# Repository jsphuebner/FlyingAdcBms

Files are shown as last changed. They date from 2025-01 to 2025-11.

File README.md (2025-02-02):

# Flying ADC BMS
This BMS senses up to 16 channels per board. Boards can be stacked to sense any number of cells. Each board has a current sensor input therefor the current sensor can be located where it is most convenient. In addition each board has two temperature sensor inputs.

For cell voltage sensing a single channel, high precision delta/sigma ADC is used in conjunction with a 16 channel multiplexer. Each cell is sensed with a differential input with an accuracy 0.5 mV. The ADC is paired with a full bridge connected to its 5V isolated power supply. This allows sending current into a low cell and also draining current from a high cell. Only small balancing currents are used over a long time thus omitting large power resistors.
Due to its architecture the cell inputs are somewhat tolerant to miswiring, i.e. a swapped cell lead or multiple cells across one input won't damage the circuitry and will instead be reported by software.

# Wiring
Each board has 17 inputs for cell taps labeled V0 to V16. The very first input of the first board is connected to B-, i.e. the negative pole of the most negative cell. V16 of the first board is connected to the positive pole of the 16th cell. The latter is also connected to V0 of the second board.
Not all channels of a board need to be used if it is more convenient

A common CAN bus and 12V supply is connected to each module. In addition each module has an enable input an output. The first enable input must be connected to 12V whenever you want the BMS to run. subsequent enable inputs are connected to the enable output of the previous module.

Further documentation can be found here: https://openinverter.org/wiki/16-cell_BMS

# OTA (over the air upgrade)
The firmware is linked to leave the 4 kb of flash unused. Those 4 kb are reserved for the bootloader
that you can find here: https://github.com/jsphuebner/stm32-CANBootloader/

When flashing your device for the first time you must first flash that bootloader. After that you can
use the ESP32 CAN module and its web interface to upload your actual application firmware.

The web interface is here: https://github.com/jsphuebner/esp32-web-interface/tree/can-backend

Binaries are here: https://github.com/jsphuebner/FlyingAdcBms/actions

# Compiling
You will need the arm-none-eabi toolchain: https://developer.arm.com/open-source/gnu-toolchain/gnu-rm/downloads
On Ubuntu type

`sudo apt-get install git gcc-arm-none-eabi`

The only external depedencies are libopencm3 and libopeninv. You can download and build these dependencies by typing

`make get-deps`

Now you can compile stm32-<yourname> by typing

`make`

And upload it to your board using a JTAG/SWD adapter, the updater.py script or the esp8266 web interface.

# Editing
The repository provides a project file for Code::Blocks, a rather leightweight IDE for cpp code editing.
For building though, it just executes the above command. Its build system is not actually used.
Consequently you can use your favority IDE or editor for editing files.

# Adding classes or modules
As your firmware grows you probably want to add classes. To do so, put the header file in include/ and the 
source file in src/ . Then add your module to the object list in Makefile that starts in line 43 with .o
extension. So if your files are called "mymodule.cpp" and "mymodule.h" you add "mymodule.o" to the list.

When changing a header file the build system doesn't always detect this, so you have to "make clean" and
then make. This is especially important when editing the "*_prj.h" files.

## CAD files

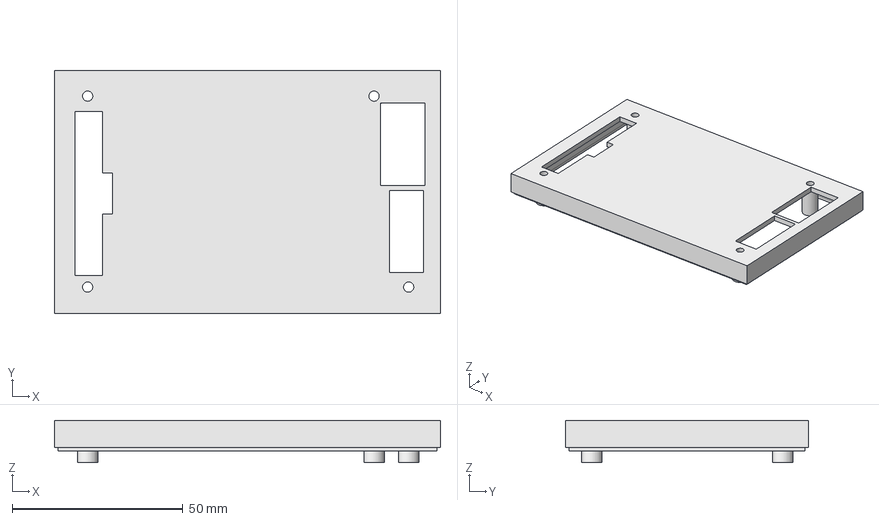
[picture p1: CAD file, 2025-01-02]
enclosure/Export/FlyingADCBMSCaseTop.step
113.0 x 71.0 x 12.3 mm

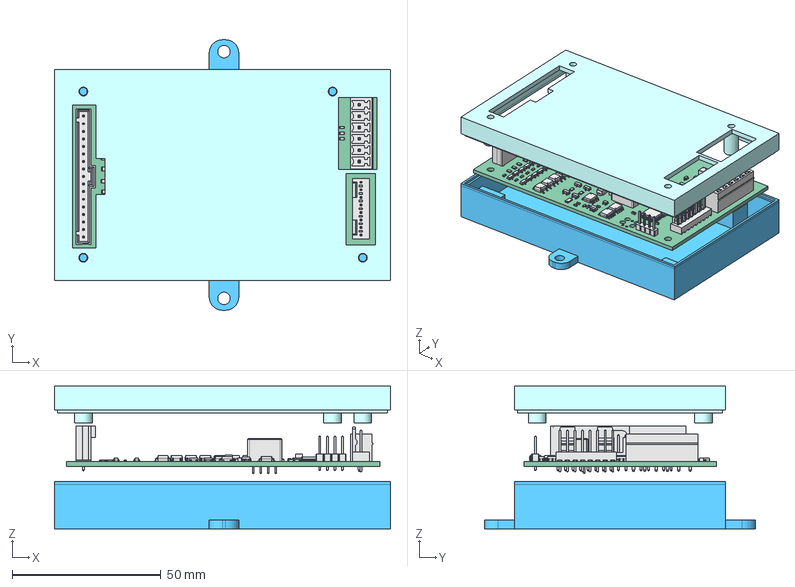
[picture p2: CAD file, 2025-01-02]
enclosure/Flying_ADC_BMS.FCStd
113.0 x 91.0 x 48.0 mm
Pcb_b294
Q14_SOT_23_87ded7d59d4a x 36
R14_R_0603_1608Metric_3bfc73a55aef x 30
R22_R_0805_2012Metric_596e45dfbf1c x 17
RN3_R_Array_Concave_4x0603_c5f54f47414b x 3
U27_SOP_4_38x41mm_P254mm_5cef88676b32 x 17
U6_SOIC_8_39x49mm_P127mm_981808474e07 x 4
J2_Molex_AE_6410_08A_b38d527fb858
L1_L_1210_3225Metric_4f8d756e5ff9
U2_SOT_23_6_b0798abddf9c x 2
C5_C_0805_2012Metric_f418098cded9 x 4
C7_C_0603_1608Metric_eb9e8be2ffff x 10
J5_PinHeader_1x04_P254mm_Vertical_e13bca67da23
D10_D_SMA_628cb4ce9e22
U15_SOT_353_SC_70_5_34e62e0b32b6
U14_LQFP_48_7x7mm_P05mm_7ef63f9fbcc2
F1_Fuse_1206_3216Metric_5dfb2dddf364
U4_SOIC_16_39x99mm_P127mm_1f1714147c6b x 2
PS1_Converter_DCDC_muRata_CRE1xxxxxx3C_THT_27c79fee6e5f[2]
J3_MCV_01x06_G_3_81mm_6525aa7bb5dd
D8_D_0805_f81e565784b3
L2_L_0805_2012Metric_366ff494121c
D6_D_SOD_323_b7a4576a8f9d x 2
CaseTop
CaseBottom

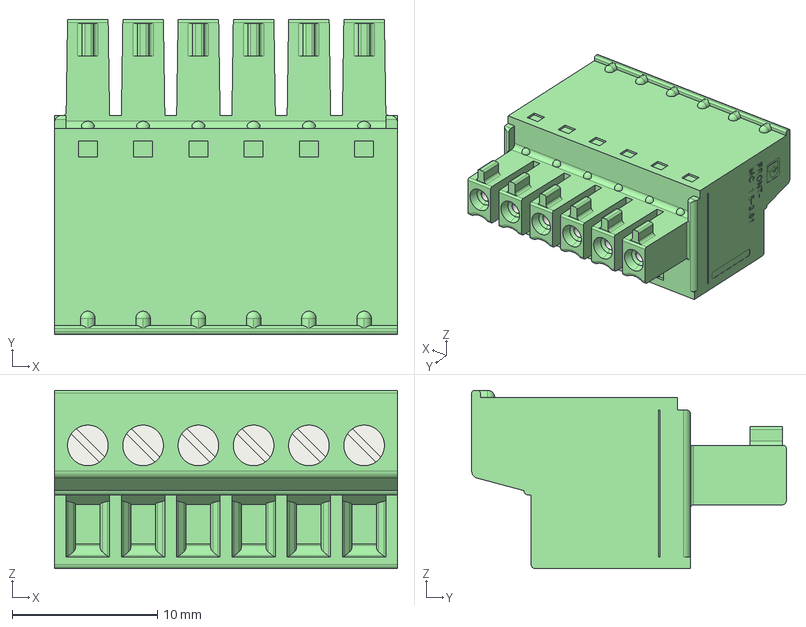
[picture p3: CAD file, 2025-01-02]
enclosure/Parts/pxc_1850709_13_FRONT-MC-1-5-6-ST-3-81_3D.stp
23.7 x 21.7 x 12.3 mm

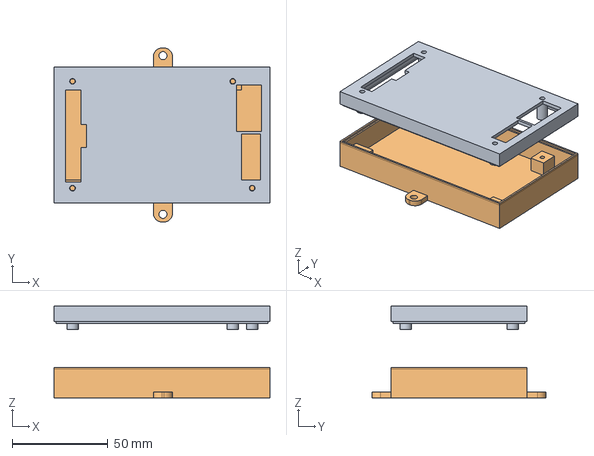
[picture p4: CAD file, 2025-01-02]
enclosure/Export/Flying_ADC_BMS_Case.step
113.0 x 91.0 x 48.0 mm
CaseTop
CaseBottom

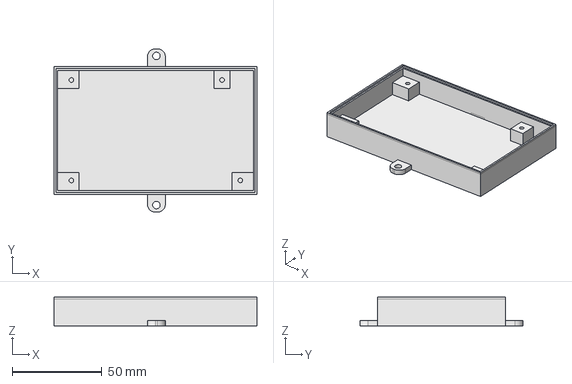
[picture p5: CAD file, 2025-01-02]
enclosure/Export/FlyingADCBMSCaseBottom.step
113.0 x 91.0 x 16.0 mm

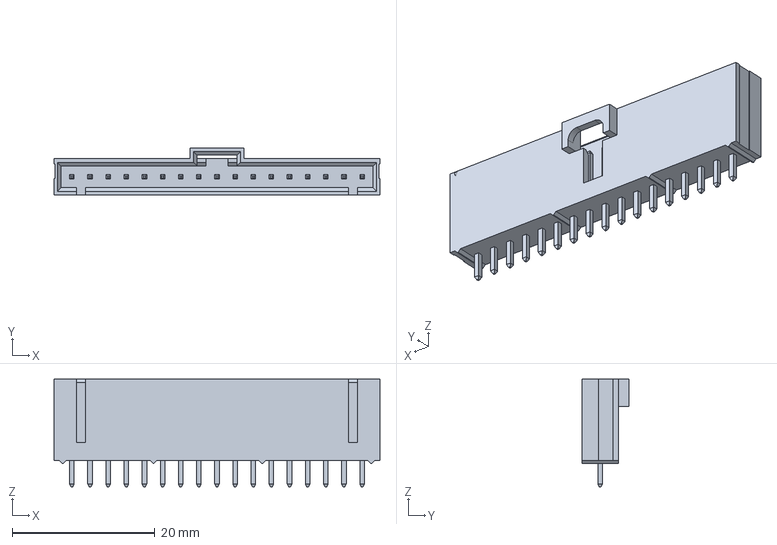
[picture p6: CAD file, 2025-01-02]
enclosure/Parts/1719710017.stp
45.6 x 6.60 x 15.1 mm

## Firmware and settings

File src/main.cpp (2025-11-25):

/*
 * This file is part of the FlyingAdcBms project.
 *
 * Copyright (C) 2025 Johannes Huebner <dev@johanneshuebner.com>
 *
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
 * You should have received a copy of the GNU General Public License
 * along with this program.  If not, see <http://www.gnu.org/licenses/>.
 */
#include <stdint.h>
#include <libopencm3/stm32/usart.h>
#include <libopencm3/stm32/rtc.h>
#include <libopencm3/stm32/can.h>
#include <libopencm3/stm32/iwdg.h>
#include <libopencm3/stm32/f1/bkp.h>
#include "stm32_can.h"
#include "canmap.h"
#include "cansdo.h"
#include "terminal.h"
#include "params.h"
#include "hwdefs.h"
#include "digio.h"
#include "hwinit.h"
#include "anain.h"
#include "param_save.h"
#include "my_math.h"
#include "errormessage.h"
#include "printf.h"
#include "stm32scheduler.h"
#include "terminalcommands.h"
#include "sdocommands.h"
#include "flyingadcbms.h"
#include "bmsfsm.h"
#include "bmsalgo.h"
#include "bmsio.h"
#include "selftest.h"

#define PRINT_JSON 0

static Stm32Scheduler* scheduler;
static CanMap* canMapExternal;
static CanMap* canMapInternal;
static BmsFsm* bmsFsm;
static CanSdo* canSdo;
HwRev hwRev;

static void CalculateCurrentLimits()
{
   float chargeCurrentLimit = BmsAlgo::GetChargeCurrent(Param::GetFloat(Param::umax),
                                                        Param::GetFloat(Param::ucellhyst),
                                                        Param::GetFloat(Param::icutoff));
   chargeCurrentLimit *= BmsAlgo::LowTemperatureDerating(Param::GetFloat(Param::tempmin));
   chargeCurrentLimit *= BmsAlgo::HighTemperatureDerating(Param::GetFloat(Param::tempmax), 50);
   Param::SetFloat(Param::chargelim, chargeCurrentLimit);

   float dischargeCurrentLimit = BmsAlgo::LimitMinimumCellVoltage(Param::GetFloat(Param::umin));
   dischargeCurrentLimit *= BmsAlgo::HighTemperatureDerating(Param::GetFloat(Param::tempmax), 53);
   Param::SetFloat(Param::dischargelim, dischargeCurrentLimit);
/*
   if (Param::GetFloat(Param::umax) < (Param::GetFloat(Param::ucellmax) - 50))
      DigIo::nextena_out.Set();
   else if (Param::GetFloat(Param::umax) >= Param::GetFloat(Param::ucellmax))
      DigIo::nextena_out.Clear();*/
}

static void CalculateSocSoh(BmsFsm::bmsstate stt, BmsFsm::bmsstate laststt)
{
   static float estimatedSoc = 0, estimatedSocAtValidSoh = -1, asDiffAfterEstimate = 0, soh = 0;
   float asDiff = Param::GetFloat(Param::chargein) - Param::GetFloat(Param::chargeout);

   if (estimatedSoc == 0)
   {
      estimatedSoc = Param::GetFloat(Param::soc);
      estimatedSocAtValidSoh = estimatedSoc;
   }

   /* if we change over from IDLE to RUN we have to stop all estimation processes
      because there is now current through the battery again, skewing open voltage readings.
      So the estimations do not get any better at this point and we store the results */
   if (laststt == BmsFsm::IDLE && stt == BmsFsm::RUN)
   {
      /* Remember the Ampere Seconds at the point of the last estimation
         in order to be prepared for the next estimation */
      asDiffAfterEstimate = asDiff;

      /* If the SoC difference was large enough we have a valid SoH */
      if (soh > 0)
      {
         float lastSoh = Param::GetFloat(Param::soh);
         //Don't just overwrite the existing SoH but average it to the existing SoH with a slow IIR filter
         soh = IIRFILTERF(lastSoh, soh, 10);
         //Store in NVRAM
         BKP_DR2 = (uint16_t)(soh * 100);
         Param::SetFloat(Param::soh, soh);
         Param::SetFloat(Param::sohpreset, soh);
         /* Remember SoC at the point of this estimation
            in order to be prepared for the next estimation */
         estimatedSocAtValidSoh = estimatedSoc;
         //BmsAlgo::SetNominalCapacity(Param::GetFloat(Param::nomcap) * soh / 100.0f);
      }
   }

   /* IDLE state means we haven't seen any current for some (configurable) time
      so cell voltage is approaching the true open circuit voltage */
   if (stt == BmsFsm::IDLE && Param::GetFloat(Param::idc) < Param::GetFloat(Param::idlethresh))
   {
      estimatedSoc = BmsAlgo::EstimateSocFromVoltage(Param::GetFloat(Param::umin));
      Param::SetFloat(Param::soc, estimatedSoc);
      //Store estimated SoC in NVRAM
      BKP_DR1 = (uint16_t)(estimatedSoc * 100);

      soh = BmsAlgo::CalculateSoH(estimatedSocAtValidSoh, estimatedSoc, asDiff - asDiffAfterEstimate);

      if (soh > 0 && estimatedSocAtValidSoh < 0)
         estimatedSocAtValidSoh = estimatedSoc;
   }
   else
   {
      float soc = BmsAlgo::CalculateSocFromIntegration(estimatedSoc, asDiff - asDiffAfterEstimate);
      Param::SetFloat(Param::soc, soc);
      BKP_DR1 = (uint16_t)(soc * 100);
   }
}

static void Ms100Task(void)
{
   static uint8_t ledDivider = 0;
   //The boot loader enables the watchdog, we have to reset it
   //at least every 2s or otherwise the controller is hard reset.
   iwdg_reset();
   float cpuLoad = scheduler->GetCpuLoad();
   Param::SetFloat(Param::cpuload, cpuLoad / 10);

   if (Param::GetInt(Param::opmode) != BmsFsm::ERROR)
      DigIo::led_out.Toggle();
   else //blink slower when an error is detected
   {
      if (ledDivider == 0)
      {
         DigIo::led_out.Toggle();
         ledDivider = 4;
      }
      else
         ledDivider--;
   }

   BmsFsm::bmsstate laststt = (BmsFsm::bmsstate)Param::GetInt(Param::opmode);
   BmsFsm::bmsstate stt = bmsFsm->Run(laststt);
   BmsIO::ReadTemperatures();

   if (bmsFsm->IsFirst())
   {
      CalculateCurrentLimits();
      CalculateSocSoh(stt, laststt);
   }

   Param::SetInt(Param::opmode, stt);
   //4 bit circular counter for alive indication
   Param::SetInt(Param::counter, (Param::GetInt(Param::counter) + 1) & 0xF);
   Param::SetInt(Param::uptime, rtc_get_counter_val());

   canSdo->TriggerTimeout(100);
   canMapExternal->SendAll();
   canMapInternal->SendAll();
}

static void RunSelfTest()
{
   static int test = 0;
   if (SelfTest::GetLastResult() == SelfTest::TestFailed) return; //do not call anymore tests
   SelfTest::TestResult result = SelfTest::RunTest(test);

   if (result == SelfTest::TestFailed)
   {
      ErrorMessage::Post((ERROR_MESSAGE_NUM)(test + 1));
      Param::SetInt(Param::lasterr, test + 1);
      Param::SetInt(Param::errinfo, SelfTest::GetErrorChannel());
   }
}

/** \brief This task runs the BMS voltage sensing */
static void ReadCellVoltages(void)
{
   int opmode = Param::GetInt(Param::opmode);
   int testchan = Param::GetInt(Param::testchan);

   if (opmode == BmsFsm::SELFTEST)
      RunSelfTest();
   else if (testchan >= 0)
      BmsIO::TestReadCellVoltage(testchan, (FlyingAdcBms::BalanceCommand)Param::GetInt(Param::testbalance));
   else if (Param::GetBool(Param::enable) && (opmode == BmsFsm::RUN || opmode == BmsFsm::IDLE))
      BmsIO::ReadCellVoltages();
   else
      FlyingAdcBms::MuxOff();
}

/** This function is called when the user changes a parameter */
void Param::Change(Param::PARAM_NUM paramNum)
{
   switch (paramNum)
   {
   case Param::reboot:
      Param::SetInt(Param::opmode, BmsFsm::REBOOT);
      break;
   case Param::sohpreset:
      Param::SetFloat(Param::soh, Param::GetFloat(Param::sohpreset));
      break;
   case Param::icc1:
   case Param::ucv1:
      BmsAlgo::SetCCCVCurve(0, Param::GetFloat(Param::icc1), Param::GetInt(Param::ucv1));
      break;
   case Param::icc2:
   case Param::ucv2:
      BmsAlgo::SetCCCVCurve(1, Param::GetFloat(Param::icc2), Param::GetInt(Param::ucv2));
      break;
   case Param::icc3:
   case Param::ucellmax:
      BmsAlgo::SetCCCVCurve(2, Param::GetFloat(Param::icc3), Param::GetInt(Param::ucellmax));
      break;
   case Param::nomcap:
      BmsAlgo::SetNominalCapacity(Param::GetFloat(Param::nomcap));
      break;
   case Param::ucellkp:
   case Param::ucellki:
      BmsAlgo::SetControllerGains(Param::GetFloat(Param::ucellkp), Param::GetFloat(Param::ucellki));
      break;
   case Param::ucellmin:
      BmsAlgo::SetMinVoltage(Param::GetInt(Param::ucellmin), Param::GetFloat(Param::dischargemax));
      break;
   default:
      for (int i = 0; i < 11; i++)
         BmsAlgo::SetSocLookupPoint(i * 10, Param::GetInt((Param::PARAM_NUM)(Param::ucell0soc + i)));
      break;
   }
}

static void LoadNVRAM()
{
   float soc = (float)BKP_DR1 / 100.0f;

   if (soc >= 0 && soc <= 100)
      Param::SetFloat(Param::soc, soc);

   if (BKP_DR2 != 0)
      Param::SetFloat(Param::soh, (float)BKP_DR2 / 100.0f);
   else
      Param::SetFixed(Param::soh, Param::Get(Param::sohpreset));
}

static void InitParameters()
{
   BmsAlgo::SetCCCVCurve(0, Param::GetFloat(Param::icc1), Param::GetInt(Param::ucv1));
   BmsAlgo::SetCCCVCurve(1, Param::GetFloat(Param::icc2), Param::GetInt(Param::ucv2));
   BmsAlgo::SetCCCVCurve(2, Param::GetFloat(Param::icc3), Param::GetInt(Param::ucellmax));
   BmsAlgo::SetMinVoltage(Param::GetInt(Param::ucellmin), Param::GetFloat(Param::dischargemax));
   BmsAlgo::SetNominalCapacity(Param::GetFloat(Param::nomcap));
   BmsAlgo::SetControllerGains(Param::GetFloat(Param::ucellkp), Param::GetFloat(Param::ucellki));
   SelfTest::SetNumChannels(Param::GetInt(Param::numchan));
   for (int i = 0; i < 11; i++)
      BmsAlgo::SetSocLookupPoint(i * 10, Param::GetInt((Param::PARAM_NUM)(Param::ucell0soc + i)));
   Param::SetInt(Param::hwrev, hwRev);
   Param::SetInt(Param::version, 4);
}

//Whichever timer(s) you use for the scheduler, you have to
//implement their ISRs here and call into the respective scheduler
extern "C" void tim2_isr(void)
{
   scheduler->Run();
}

extern "C" int main(void)
{
   clock_setup(); //Must always come first
   rtc_setup();
   hwRev = detect_hw();
   ANA_IN_CONFIGURE(ANA_IN_LIST);
   DIG_IO_CONFIGURE(DIG_IO_LIST);
   #ifdef HWV1
   spi_setup(); //in case we use V1 hardware
   DigIo::led_out.Configure(GPIOB, GPIO1, PinMode::OUTPUT);
   #endif // HWV1
   DigIo::selfena_out.Set();
   AnaIn::Start(); //Starts background ADC conversion via DMA
   write_bootloader_pininit(); //Instructs boot loader to initialize certain pins
   //JTAG must be turned off as it steals PB4
   gpio_primary_remap(AFIO_MAPR_SWJ_CFG_JTAG_OFF_SW_ON, 0);

   nvic_setup(); //Set up some interrupts
   parm_load(); //Load stored parameters

   Stm32Scheduler s(TIM2); //We never exit main so it's ok to put it on stack
   scheduler = &s;
   //Initialize CAN1, including interrupts. Clock must be enabled in clock_setup()
   Stm32Can c(CAN1, CanHardware::Baud500);
   CanMap cmi(&c, false);
   CanMap cme(&c);
   canMapInternal = &cmi;
   canMapExternal = &cme;
   CanSdo sdo(&c, &cme);
   canSdo = &sdo;

   BmsFsm fsm(&cmi, &sdo);
   bmsFsm = &fsm;
   BmsIO::SetBmsFsm(&fsm);

   TerminalCommands::SetCanMap(canMapExternal);
   SdoCommands::SetCanMap(canMapExternal);

   s.AddTask(BmsIO::MeasureCurrent, 5);
   s.AddTask(ReadCellVoltages, 25);
   s.AddTask(BmsIO::SwitchMux, 2); //This must be added after ReadCellVoltages() to avoid an additional 2 ms delay
   s.AddTask(Ms100Task, 100);

   InitParameters();

   LoadNVRAM();

   while(1)
   {
      char c = 0;
      CanSdo::SdoFrame* sdoFrame = sdo.GetPendingUserspaceSdo();

      if (sdo.GetPrintRequest() == PRINT_JSON)
      {
         TerminalCommands::PrintParamsJson(&sdo, &c);
      }
      if (0 != sdoFrame)
      {
         SdoCommands::ProcessStandardCommands(sdoFrame);
         sdo.SendSdoReply(sdoFrame);
      }
   }

   return 0;
}

/* to solve linker warning, see https://openinverter.org/forum/viewtopic.php?p=64546#p64546 */
extern "C" void __cxa_pure_virtual() { while (1); }

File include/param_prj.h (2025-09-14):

/*
 * This file is part of the FlyingAdcBms project.
 *
 * Copyright (C) 2022 Johannes Huebner <dev@johanneshuebner.com>
 *
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
 * You should have received a copy of the GNU General Public License
 * along with this program.  If not, see <http://www.gnu.org/licenses/>.
 */

/* This file contains all parameters used in your project
 * See main.cpp on how to access them.
 * If a parameters unit is of format "0=Choice, 1=AnotherChoice" etc.
 * It will be displayed as a dropdown in the web interface
 * If it is a spot value, the decimal is translated to the name, i.e. 0 becomes "Choice"
 * If the enum values are powers of two, they will be displayed as flags, example
 * "0=None, 1=Flag1, 2=Flag2, 4=Flag3, 8=Flag4" and the value is 5.
 * It means that Flag1 and Flag3 are active -> Display "Flag1 | Flag3"
 *
 * Every parameter/value has a unique ID that must never change. This is used when loading parameters
 * from flash, so even across firmware versions saved parameters in flash can always be mapped
 * back to our list here. If a new value is added, it will receive its default value
 * because it will not be found in flash.
 * The unique ID is also used in the CAN module, to be able to recover the CAN map
 * no matter which firmware version saved it to flash.
 * Make sure to keep track of your ids and avoid duplicates. Also don't re-assign
 * IDs from deleted parameters because you will end up loading some random value
 * into your new parameter!
 * IDs are 16 bit, so 65535 is the maximum
 */

 //Define a version string of your firmware here
#define VERSION 0.29

/* Entries must be ordered as follows:
   1. Saveable parameters (id != 0)
   2. Temporary parameters (id = 0)
   3. Display values
 */
//Next param id (increase when adding new parameter!): 62
//Next value Id: 2105
/*              category     name         unit       min     max     default id */
#define PARAM_LIST \
    PARAM_ENTRY(CAT_BMS,     gain,        "mV/dig",  1,      1000,   586,    3   ) \
    PARAM_ENTRY(CAT_BMS,     correction0, "ppm",     -10000, 10000,  -1250,  14  ) \
    PARAM_ENTRY(CAT_BMS,     correction1, "ppm",     -10000, 10000,  1500,   15  ) \
    PARAM_ENTRY(CAT_BMS,     correction15,"ppm",     -10000, 10000,  1000,   16  ) \
    PARAM_ENTRY(CAT_BMS,     numchan,     "",        1,      16,     16,     4   ) \
    PARAM_ENTRY(CAT_BMS,     balmode,     BALMODE,   0,      3,      0,      5   ) \
    PARAM_ENTRY(CAT_BMS,     ubalance,    "mV",      0,      4500,   4500,   30  ) \
    PARAM_ENTRY(CAT_BMS,     idlewait,    "s",       0,      100000, 60,     12  ) \
    PARAM_ENTRY(CAT_BMS,     turnoffwait, "s",       0,      999999, 72000,  58  ) \
    PARAM_ENTRY(CAT_BMS,     idlethresh,  "A",       0,      10,     0.5,    55  ) \
    PARAM_ENTRY(CAT_BAT,     dischargemax,"A",       1,      2047,   200,    32  ) \
    PARAM_ENTRY(CAT_BAT,     nomcap,      "Ah",      0,      1000,   100,    9   ) \
    PARAM_ENTRY(CAT_BAT,     icc1,        "A",       1,      2000,   50,     43  ) \
    PARAM_ENTRY(CAT_BAT,     icc2,        "A",       1,      2000,   30,     44  ) \
    PARAM_ENTRY(CAT_BAT,     icc3,        "A",       1,      2000,   20,     45  ) \
    PARAM_ENTRY(CAT_BAT,     icutoff,     "A",       1,      200,    2,      57  ) \
    PARAM_ENTRY(CAT_BAT,     ucv1,        "mV",      3000,   4500,   3900,   46  ) \
    PARAM_ENTRY(CAT_BAT,     ucv2,        "mV",      3000,   4500,   4000,   47  ) \
    PARAM_ENTRY(CAT_BAT,     ucellmax,    "mV",      1000,   4500,   4200,   29  ) \
    PARAM_ENTRY(CAT_BAT,     ucellmin,    "mV",      1000,   4500,   3300,   28  ) \
    PARAM_ENTRY(CAT_BAT,     ucellhyst,   "mV",      1000,   4500,   4150,   56  ) \
    PARAM_ENTRY(CAT_BAT,     ucellkp,     "",        0.03,   100,    1,      59  ) \
    PARAM_ENTRY(CAT_BAT,     ucellki,     "",        0.03,   100,    1,      60  ) \
    PARAM_ENTRY(CAT_BAT,     ucell0soc,   "mV",      2000,   4500,   3300,   17  ) \
    PARAM_ENTRY(CAT_BAT,     ucell10soc,  "mV",      2000,   4500,   3400,   18  ) \
    PARAM_ENTRY(CAT_BAT,     ucell20soc,  "mV",      2000,   4500,   3450,   19  ) \
    PARAM_ENTRY(CAT_BAT,     ucell30soc,  "mV",      2000,   4500,   3500,   20  ) \
    PARAM_ENTRY(CAT_BAT,     ucell40soc,  "mV",      2000,   4500,   3560,   21  ) \
    PARAM_ENTRY(CAT_BAT,     ucell50soc,  "mV",      2000,   4500,   3600,   22  ) \
    PARAM_ENTRY(CAT_BAT,     ucell60soc,  "mV",      2000,   4500,   3700,   23  ) \
    PARAM_ENTRY(CAT_BAT,     ucell70soc,  "mV",      2000,   4500,   3800,   24  ) \
    PARAM_ENTRY(CAT_BAT,     ucell80soc,  "mV",      2000,   4500,   4000,   25  ) \
    PARAM_ENTRY(CAT_BAT,     ucell90soc,  "mV",      2000,   4500,   4100,   26  ) \
    PARAM_ENTRY(CAT_BAT,     ucell100soc, "mV",      2000,   4500,   4200,   27  ) \
    PARAM_ENTRY(CAT_BAT,     sohpreset,   "%",       10,     100,    100,    53  ) \
    PARAM_ENTRY(CAT_SENS,    idcgain,     "dig/A",  -1000,   1000,   10,     6   ) \
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

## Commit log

2023-02-11 Balance longer and fixed balance status display
    [main.cpp, param_prj.h]
2023-04-21 Added high level BMS functions
    [temp_sensors.ods]
2023-05-22 Mux control via GPIO pins instead of SPI
2023-08-18 Added gain correction for first two and last channel Made SoC lookup table configurable Increased number of submodules to 8
    [flyingadcbms.cpp, main.cpp]
2023-09-05 Calculate min and max temperature Rearranged CAN messages Balancing to pack average, not to local module average
2023-09-07 Made min/max cell voltage configurable Balancing only with low current flow Balancing mode selectable: none, additive, dissipative, both
2023-09-07 Made current limits variable
2023-09-27 Make SoC dependent charge current limit configurable
2023-09-29 Increased sample rate of current sensor to measure 50 Hz draw correctly
    [main.cpp, param_prj.h]
2024-05-02 get rid of linker error
    [main.cpp]
2024-05-22 Replaced SoC based charge curve by 3 consecutive CC/CV profiles
    [main.cpp, param_prj.h]
2024-06-06 Redesigned addressing scheme to require less configuration
    [param_prj.h]
2024-10-25 Allow specifying a test channel that is then continously converted Update to latest libopeninv Simplify mux code Add more delay after selecting a new channel by issuing an I2C transfer Make sure ther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
2025-01-02 Added enclosure
    [1719710017.stp, FlyingADCBMSCaseBottom.step, FlyingADCBMSCaseTop.step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]
2025-01-06 More universal temperature sensor parameters and proper min/max handling
2025-01-06 Implemented high and low temperature limits
2025-02-01 Selftest error now turns off "enable". Can get out of error state by turning on enable Renamed RUNBALANCE state to IDLE
    [main.cpp, param_prj.h, selftest.cpp]
2025-02-02 Moved some routines to bmsio class
2025-02-02 Improved SoC and SoH calculation
    Using integrated NVRAM to preserve the values over reboots
    [hwinit.cpp, main.cpp, param_prj.h]
2025-02-02 Sensor lookup tables no longer needed
    [temp_sensors.ods]
2025-02-12 Allow testing balancer Line up BalanceCommand enum with UI balmode Run v2.3 hardware at higher I2C speed Poll balancer pins and only change if needed Corrected HW detection More delay in self test
    [bmsio.cpp, flyingadcbms.cpp, hwinit.cpp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]
2025-02-14 Higher priority for scheduler (just in case). Refactoring
2025-02-25 Never turn off BMS when enable input is still on
2025-02-25 Never turn off BMS when enable input is still on (issue #1)
    [flyingadcbms.cpp, hwinit.cpp, param_prj.h]
2025-04-09 New sweep pattern, 0, 2, 4,...15, 13,..., 1 Only shut down when enable pin is low Renamed errchan to errinfo giving some hint about the error Corrected default value for tempsns
    [bmsio.cpp, main.cpp, param_prj.h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]
2025-06-02 More explicit dead time generation of 2 ms Use signed value for temperatures
2025-06-02 Assigned one more bit to cell voltage fields because they are treated signed
2025-06-05 Always issue "all pins as output" command before every balancing command Clear mux control pins before switching them to output Don't set cell nominal capacity to our SoH corrected one, for now
    [flyingadcbms.cpp, main.cpp, param_prj.h]
2025-07-04 Added charging cutoff voltage and current Reduced controller gains for voltage controllers because they were oscillating Added parameter for idle current threshold Allowing faster discharge on v2.4 h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
    [bmsio.cpp, flyingadcbms.cpp, main.cpp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]
2025-09-14 Use PI controller for low voltage derating Use floating point PI controller Make controller gains configurable Allow rebooting sub modules Turn off sub module as soon as enable signal is lost Make id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
    [main.cpp, param_prj.h, selftest.cpp]
2025-11-25 Limit max balancing voltage to 100% point Fixed SOH calculation
    [bmsio.cpp, hwinit.cpp, main.cpp]

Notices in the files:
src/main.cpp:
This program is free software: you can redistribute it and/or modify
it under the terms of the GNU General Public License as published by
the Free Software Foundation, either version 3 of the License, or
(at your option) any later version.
